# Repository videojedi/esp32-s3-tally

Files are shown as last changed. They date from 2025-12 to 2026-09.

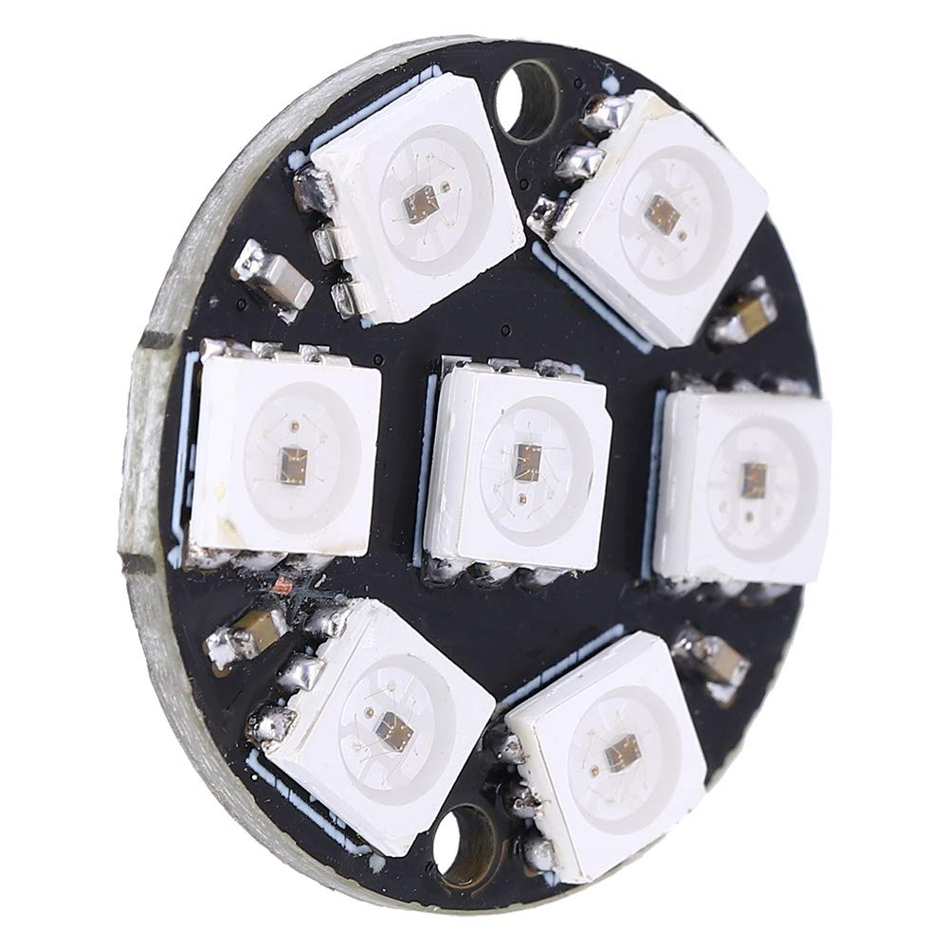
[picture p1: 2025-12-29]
3d files/7LEDring.png

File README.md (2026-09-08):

# ESP32-S3 TSL Tally Light

A TSL 3.1 protocol tally light with web-based configuration, built for ESP32-S3 with W5500 Ethernet.

**Video Walrus 2026**

## Features

- **TSL 3.1 Protocol Support** - Receives multicast UDP tally commands, including brightness
- **Tally Arbiter listener** - Alternative source: follow a device in a Tally Arbiter server (socket.io, like the stock listener clients)
- **Dual-Core Processing** - UDP listener runs on core 0 for reliable packet reception
- **Web Configuration Interface** - Configure all settings via browser
- **Network Priority** - Ethernet preferred, WiFi fallback, AP mode for configuration
- **Auto Device Discovery** - Automatically finds all tally lights on the network via mDNS
- **Bulk Control** - Test all devices simultaneously from any tally's web interface
- **Captive Portal** - Automatic configuration page popup in AP mode
- **Unique Device Identity** - Each device gets a unique hostname based on MAC address
- **mDNS Support** - Access via hostname.local (e.g., `http://Tally-AABBCC.local`)
- **OTA Updates** - Over-the-air firmware updates from the Video Walrus release manifest, or via PlatformIO
- **Persistent Settings** - Configuration stored in NVS flash
- **Factory Reset** - Hold BOOT button for 3 seconds, or use web interface button

## Hardware

### Components

| Component | Description |
|---|---|
| ESP32-S3 DevKitC-1 | Main microcontroller |
| W5500 Ethernet Module | SPI Ethernet PHY |
| WS2812B LED Ring | 7 addressable RGB LEDs (1 middle + 6 ring, e.g. NeoPixel Jewel) |

### Pin Configuration

| Function | GPIO |
|---|---|
| LED Data | 16 |
| ETH CS | 14 |
| ETH SCLK | 13 |
| ETH MISO | 12 |
| ETH MOSI | 11 |
| ETH RST | 9 |
| Factory Reset | 0 (BOOT button) |

### W5500 SPI Ethernet

The W5500 module connects via SPI. These defines must be set before including ETH.h:
- `ETH_PHY_TYPE` = ETH_PHY_W5500
- `ETH_PHY_ADDR` = 1
- `ETH_PHY_CS` = 14 (Chip Select)
- `ETH_PHY_IRQ` = -1 (polled, no interrupt pin)
- `ETH_PHY_RST` = 9 (Reset)
- `ETH_PHY_SPI_HOST` = SPI2_HOST
- `ETH_PHY_SPI_SCK/MISO/MOSI` = 13/12/11

## Web Interface

Open the device IP or `http://<hostname>.local`. Three tabs:

- **Operation** (default): tally state, TSL text, TSL data counter, test buttons, network device list.
- **Configuration**: Tally Source, TSL Settings or Tally Arbiter, and LED Settings.
- **System**: device identity, clock and firmware update, Network and WiFi settings, settings lock, factory reset.

The header shows hostname, IP and connection on every tab, and the page background follows the tally colour. An Auto / Light / Dark switch above the tabs sets the page theme (Auto follows the browser or OS setting); the choice is stored in the browser and also applies to native form controls. The last tab used is remembered in the browser; in AP mode the page opens on System. Configuration and System share one form, so Save on either tab saves both.

**Save** applies most settings immediately: TSL address, max brightness and LED animation take effect without a reboot, and a toast confirms it. The device reboots only when a boot-time setting changed: hostname, IP configuration, WiFi, or the TSL multicast address and port. Hostnames are reduced to letters, digits and hyphens; IP fields that do not parse are ignored. With a settings PIN set, Save asks for it once per browser session (see [Settings Lock](#settings-lock)).

### Status

Operation tab: tally state (Off/Green/Red/Yellow), the TSL text label, and a data line: with the TSL source, packets received for this device's address, the sender and how long ago the last one arrived; with Tally Arbiter, the server, connection state, the assigned device and the update count. Polled every second. System tab: connection type, IP, hostname, MAC, clock (UTC, from SNTP), settings lock state, firmware version with **Check** / **Install** update buttons. The footer shows the firmware build date and time.

### Test Buttons

Manual tally control buttons for testing (momentary - hold to activate):
- **GREEN** - Preview/safe (state 1)
- **RED** - Program/on-air (state 2)
- **YELLOW** - Both tallies active (state 3)

Releasing a button, or dragging off it, returns the light to the last state and brightness received from the switcher (Off if nothing has been received since boot).

### Network Devices

Automatically discovers and displays other tally lights on your network:
- **Auto-discovery** - Devices are scanned on page load, and the firmware rescans in the background every 60 seconds (Ethernet/WiFi only)
- **Scan Network** - Manual refresh button; results are cached for 10 seconds
- Device list shows hostname, TSL address, IP, and a live status dot (polled every 5 seconds)
- **Open** link on each device opens its configuration page
- **Bulk control buttons** - **All GREEN**, **All RED**, **All OFF** set every discovered device plus this one. These are latching, not momentary

### Disco Mode

Type `disco` anywhere on the page (outside a text field) to run a 30-second rainbow party on this device and every discovered device. Tap **Stop** on the overlay to end it early.

### Tally Source

| Setting | Description | Default |
|---|---|---|
| Source | `TSL 3.1 (UDP multicast)` or `Tally Arbiter` (reboots) | TSL 3.1 |

### Tally Arbiter

The tally can be a [Tally Arbiter](https://github.com/josephdadams/TallyArbiter) listener client instead of a TSL receiver. It connects to the server over socket.io (port 4455), registers as a listener and follows one of the server's devices: **program lights red, preview green, both yellow**; other bus types (aux) are ignored. Tally Arbiter has no brightness, so Max Brightness applies.

| Setting | Description | Default |
|---|---|---|
| Server | Hostname or IP of the Tally Arbiter server. **Find server** lists servers announcing `_tally-arbiter._tcp` over mDNS (reboots) | |
| Port | Server port (reboots) | 4455 |
| Device | The Tally Arbiter device to follow, from the list the server sent. **Refresh device list** re-reads it. `Assign from Tally Arbiter` lets the server pick (its first device); applies live | Assign from Tally Arbiter |

The tally appears in Tally Arbiter's listener list as `Video Walrus <hostname>`. **Reassign** and **Flash** from the producer page work: a reassignment is stored on the tally and survives reboots, a flash blinks the ring white three times and returns to the current state. If the server goes away the ring holds its last state and the Operation tab shows "Not connected"; the tally reconnects on its own when the server is back.

### TSL Settings

| Setting | Description | Default |
|---|---|---|
| TSL Address | Tally address 0-126 (applies live) | 0 |
| Multicast Address | TSL multicast group, 224-239.x.x.x (reboots) | 239.1.2.3 |
| TSL Port | UDP port (reboots) | 8901 |

### LED Settings

| Setting | Description | Default |
|---|---|---|
| Max Brightness | LED brightness limit (1-255), applies live | 50 |
| LED Animation | How an active tally is drawn: Solid or Spin, applies live | Solid |

TSL brightness levels map to the LEDs as a fraction of Max Brightness:

| TSL brightness | LED output |
|---|---|
| 0 | Off (dark) |
| 1 | ⅓ of max |
| 2 | ⅔ of max |
| 3 | Max brightness |

**LED Animation** controls how Green, Red and Yellow are shown on the ring. **Solid** lights all seven LEDs. **Spin** keeps the middle LED on at the tally colour, holds the outer six at a dim level and sweeps a bright point with a fading tail round them (one revolution every 0.8 s). Off is always dark. The firmware assumes the middle LED is first in the data chain (`CENTER_LED 0` in main.cpp); set it to 6 if the ring is wired before the middle.

### Network Settings

Hostname, DHCP or static IP (address, gateway, subnet, DNS). Applies to Ethernet and WiFi. Changes here reboot the device.

### WiFi Settings

| Setting | Description |
|---|---|
| WiFi | Disabled, or Enabled (used when Ethernet is down) |
| SSID | WiFi network name |
| Scan for Networks | Lists nearby networks, strongest first, one row per SSID with a lock for secured networks. Tap a row to fill in the SSID. Works in Ethernet, WiFi and AP mode |
| Password | WiFi password. Never shown once stored: leave blank to keep it, type to replace it (a **Show while typing** toggle appears), or tick **Network has no password** to clear it |

Changes here reboot the device.

### Settings Lock

An optional PIN (4 to 16 characters) gates every change made over the network: Save, Reset Defaults, firmware Install, the test buttons, bulk buttons and disco. Status and configuration reads stay open so a monitor wall can watch. The page asks for the PIN once per browser session and sends it with each change; wrong or missing gives HTTP 401. Changing or removing the PIN asks for the current one again, unless the unit was unlocked from its BOOT button. Bulk buttons and disco send this device's PIN to the other tallies they drive, so use the same PIN across a fleet.

**Forgotten PIN:** hold BOOT on the unit for 3 seconds (the ring blinks red) and release: the settings are unlocked for 10 minutes without the PIN, shown on the System tab. Anyone at the box can reflash it over USB anyway, so this costs nothing. Keep holding for 10 seconds to factory reset instead.

The PIN travels over plain HTTP. It protects against accidents and the curious on the LAN, not a determined attacker; put the device on a trusted or segmented network, as with any broadcast control gear.

## Network Modes

The device uses a single network interface at a time for simplicity and reliability:

### Priority Order

1. **Ethernet** - Used exclusively if a link comes up within 10 seconds of boot (best for production)
2. **WiFi** - Falls back if Ethernet unavailable (10 second connect timeout)
3. **AP Mode** - Creates access point if both fail (for initial configuration)

### AP Mode (Fallback)

When no network is available, the device creates its own access point:
- SSID: `Tally-XXYYZZ-Setup` (unique per device)
- Password: `tallytally`
- IP: `192.168.4.1`
- LED indicator: cyan spin, then dim cyan
- **Captive Portal** - Configuration page opens automatically when you connect
- TSL reception, mDNS and PlatformIO OTA are disabled in AP mode

## LED Indicators

| Pattern | Meaning |
|---|---|
| Orange spin | Waiting for Ethernet link |
| Purple spin | Connecting to WiFi |
| Cyan spin | AP mode starting |
| Dim cyan | AP mode active |
| Red blink (BOOT held 3 s) | Release now to unlock the settings for 10 minutes; keep holding for factory reset |
| Red blink, faster (BOOT held 7 s) | Factory reset in 3 seconds, release to abort |
| Blue, then reboot | Factory reset done (BOOT held 10 s) |
| Red, green, blue cycle | Network connected, ready |
| Purple (solid) | Firmware update in progress |
| Green (solid) then reboot | Firmware update succeeded |
| Red (2 s) | Firmware update failed, then back to the current tally |

The boot stages use the same spin animation as the **LED Animation** setting: the middle LED stays on in the stage colour, the outer six glow dimly and a bright point with a fading tail sweeps round them.

### Tally Colors

| State | Color | Description |
|---|---|---|
| 0 | Off (black) | No tally |
| 1 | Green | Preview/safe (tally 1) |
| 2 | Red | Program/on-air (tally 2) |
| 3 | Yellow | Both preview and program |

## TSL 3.1 Protocol

The device listens for TSL 3.1 UMD protocol messages on the configured multicast address and port. Only packets whose address matches the configured TSL Address are acted on.

### Message Format

| Byte | Description |
|---|---|
| 0 | Address + 128 |
| 1 | Control byte (tally + brightness) |
| 2-17 | 16-character text label |

### Control Byte

| Bits | Description |
|---|---|
| 0 | Tally 1 → Green |
| 1 | Tally 2 → Red (both set → Yellow) |
| 2-3 | Tally 3 and 4 (ignored) |
| 4-5 | Brightness (0-3) |

The text label is filtered to printable ASCII and trimmed.

## API Endpoints

| Endpoint | Method | Description |
|---|---|---|
| `/` | GET | Configuration page (static; fills itself from `/api/config` and `/status`) |
| `/status` | GET | JSON status (tally, text, IP, connection, TSL packet count since boot, age and sender) |
| `/api/config` | GET | JSON of every setting plus hostname, MAC, AP details, firmware and build; in Tally Arbiter mode also `taDevices` (the server's device list) and `taDeviceName` |
| `/info` | GET | JSON device info (hostname, MAC, TSL address, firmware, build) |
| `/test?state=N` | GET | Set tally state (0-3) at max brightness |
| `/test?restore=1` | GET | Return to the last state received over TSL |
| `/api/unlock?pin=N` | GET | `{"ok":true}` if the PIN is right, no PIN is set, or the unit is physically unlocked |
| `/api/ta-scan` | GET | Tally Arbiter servers found over mDNS: `{"servers":[{"host","ip","port"}]}` |
| `/discover` | GET | Scan network (cached 10 s) and return found tally devices |
| `/api/wifi-scan` | GET | Start an async WiFi scan (`?start=1`) or return its result; `{"scanning":true}` while running |
| `/disco?duration=N` | GET | Start disco mode for N seconds (1-120, default 30) |
| `/disco-stop` | GET | Stop disco mode and restore the tally state |
| `/api/check-update` | GET | Fetch the release manifest; returns current, latest, date, notes, `error` and `clock` |
| `/api/update` | GET | Download, verify signature, install |
| `/api/update-status` | GET | `fw`, `inProgress`, `error` for the install in progress |
| `/save` | POST | Save settings; applies live, or reboots if network, hostname or TSL socket settings changed |
| `/reset` | GET | Factory reset and reboot |

`/status`, `/test`, `/info`, `/api/unlock`, `/api/update-status`, `/disco` and `/disco-stop` send `Access-Control-Allow-Origin: *` so one tally's page can drive the others. With a settings PIN set, `/save`, `/reset`, `/test`, `/disco`, `/disco-stop` and `/api/update` need `pin=<PIN>` (query or form field) and answer 401 without it. `/api/config` reports `passSet` and `pinSet` instead of the values.

In AP mode, the captive-portal probe URLs (`/generate_204`, `/ncsi.txt`, `/connecttest.txt`, `/hotspot-detect.html`, `/library/test/success.html`) and any unknown path redirect to `/`.

### Status Response

```json
{
  "tally": "Green",
  "text": "CAM 1",
  "ip": "192.168.1.100",
  "connection": "Ethernet",
  "pkts": 1234,
  "age": 480,
  "from": "192.168.1.10",
  "time": 1788950000,
  "pinSet": false,
  "phys": false,
  "physLeft": 0,
  "src": 0,
  "taConn": false,
  "taHost": "",
  "taPort": 4455,
  "taDevice": ""
}
```

`src` is 0 for TSL, 1 for Tally Arbiter; `taConn` and `taDevice` (the device name) describe the Tally Arbiter connection, and `pkts`/`age` then count `device_states` updates from the server.

`pkts` counts packets addressed to this device since boot, `age` is milliseconds since the last one, `from` is its sender. `time` is the SNTP clock (Unix seconds, 0 until synced). `pinSet` says a settings PIN exists, `phys` that the unit was unlocked from its BOOT button, with `physLeft` seconds remaining.

### Info Response

```json
{
  "hostname": "Tally-AABBCC",
  "ip": "192.168.1.100",
  "mac": "AA:BB:CC:DD:EE:FF",
  "tslAddress": 1,
  "tallyState": "Green",
  "tallyText": "CAM 1",
  "connection": "Ethernet",
  "firmware": "1.0.10",
  "build": "Sep  2 2026 18:40:12"
}
```

### Discover Response

```json
{
  "devices": [
    {"hostname": "Tally-112233", "ip": "192.168.1.51", "tslAddress": 2},
    {"hostname": "Tally-445566", "ip": "192.168.1.52", "tslAddress": 3}
  ],
  "count": 2
}
```

## OTA Updates

### From the web page

Click **Check** on the System tab. If a newer version exists a popup lists the release notes with **Install** and **Later**; Install shows progress and reloads the page when the device is back. After an update, the page shows a "What's new" popup once per browser.

The device fetches `https://videowalrus-releases.s3.us-east-1.amazonaws.com/tsl-tally-update.json` (URL in [src/main.cpp](src/main.cpp)), compares `version` with its own, shows the release notes, and on Install downloads the binary at `url`.

Manifest format:

```json
{"version":"1.2.0","url":"https://videowalrus-releases.s3.us-east-1.amazonaws.com/tsl-tally-1.2.0.bin",
 "md5":"...","sha256":"...","sig":"<base64 ECDSA-SHA256 signature>","size":1325000,
 "release_date":"2026-09-07","notes":["...","..."]}
```

### Update security

- **Transport.** Manifest and binary are fetched over TLS validated against Amazon's root certificates compiled into the firmware ([src/certs.h](src/certs.h)). A device that cannot validate the chain refuses to talk. Validation needs the clock, so the device syncs SNTP when online and the update check waits until it has; the System tab shows the clock.
- **Authenticity.** Every release is signed with an ECDSA P-256 key that never enters the repo. `release.sh` reads it from the macOS Keychain (generic password `videowalrus-tsl-tally-signing`, PEM base64-encoded) and falls back to a PEM file at `~/.config/videowalrus/tsl-tally-signing.key` or `SIGNING_KEY=<file>`. The public key is compiled in ([src/signing_key.h](src/signing_key.h)). The device hashes the binary as it streams into the passive partition and verifies the signature before the image is marked bootable; a mismatch aborts and the running firmware stays. This holds even if the bucket or the AWS credentials are compromised.
- **Manifests without a signature are refused** by firmware 1.2.0 and later. `release.sh` checks that the compiled-in public key matches the private key before building, so a release can never be signed with a key the devices don't trust.
- **Key loss.** Losing the private key means no further OTA updates to devices in the field; they would need USB reflashing with a new public key. The login Keychain lives on one Mac, so keep a second copy somewhere encrypted and off the machine. The tally key is separate from the TSL relay's.
- **Older firmware.** 1.1.0 verifies MD5 only and ignores the signature fields, so it can still update to a signed release. 1.0.12 and earlier update from GitHub, where the v1.1.0 release remains as the stepping stone.

**Firmware 1.0.12 and earlier** looks for updates on GitHub releases instead (`https://api.github.com/repos/videojedi/esp32-s3-tally/releases/latest`, asset `firmware.bin`). The v1.1.0 GitHub release exists so those devices can reach the manifest-based firmware; after that they update from S3 like everything else.

### PlatformIO OTA

For development or manual updates:

- Hostname: Configured device hostname
- Password: `password`
- Port: Default (3232)

#### Single Device Update

```bash
# Set target IP and upload
TALLY_IP=192.168.1.100 pio run -t upload -e ota

# Or use mDNS hostname
TALLY_IP=Tally-AABBCC.local pio run -t upload -e ota
```

#### Bulk Update All Devices

Use the included script to update all tally lights on the network:

```bash
# Provide any known device IP - it discovers the rest
./ota-update-all.sh 192.168.1.100
```

The script will:
1. Build the firmware
2. Query the device to discover all tallies on the network
3. Show the device list and ask for confirmation
4. Update each device via OTA
5. Report success/failure summary

### Creating Releases

```bash
./release.sh 1.1.0 "Tabbed web page" "Light and dark themes"
```

Bumps `FIRMWARE_VERSION`, builds, signs the binary, commits, tags, pushes, uploads `tsl-tally-<version>.bin` to S3 and rewrites the manifest with version, URL, MD5, SHA-256, signature, size, date and the notes given as arguments. Safe to rerun for the same version. Needs the AWS CLI and a `.env` in the project root with `AWS_ACCESS_KEY_ID`, `AWS_SECRET_ACCESS_KEY`, `AWS_REGION` and `S3_BUCKET` (not committed).

`GITHUB=1 ./release.sh ...` also creates a GitHub release with `firmware.bin` attached, for devices still on 1.0.12 or earlier.

## Performance and Packet Rates

The receiver drains every queued packet each pass, only looks at the address byte of frames for other addresses, and redraws the LEDs only when the state, brightness or text changed, so a switcher repeating all 127 addresses several times a second costs the tally almost nothing. Measured on the bench with unicast frames it keeps a median response under 50 ms at 1200 packets/s and stays usable at 2500/s.

**Multicast over WiFi is the limit, not the tally.** An access point forwards multicast to WiFi clients at its lowest basic rate, often 1 to 6 Mbit/s on 2.4 GHz, without acknowledgements. A few hundred small TSL frames a second already fill that, frames get dropped and the light lags by seconds; at around 1000 frames/s it stops responding. The same flood as unicast is fine. If a tally on WiFi is slow when the switcher is busy:

- Use Ethernet for that tally (no such limit on the wire).
- Turn on multicast-to-unicast conversion on the access point (UniFi "Multicast enhancement", Cisco/Aruba "multicast to unicast", Ruckus "directed multicast").
- Point the sender at the tally's IP instead of the group. The tally accepts unicast TSL on its port as well as the multicast group.
- Lower the sender's repeat rate if it has one.
- Or run the tally in Tally Arbiter mode, which is a unicast TCP connection.

WiFi modem sleep is disabled in the firmware because it adds tens of milliseconds to every received frame and drops multicast.

## Factory Reset

### Hardware Reset

With the unit running, hold BOOT (GPIO 0). After 3 seconds the ring blinks red; keep holding and the blink speeds up at 7 seconds. At 10 seconds the ring turns blue, settings are erased and the unit reboots into AP mode. Release before 10 seconds and nothing is erased (releasing after 3 seconds unlocks the settings instead, see [Settings Lock](#settings-lock)). Do not hold BOOT while powering on or pressing RESET: GPIO 0 low at reset enters the USB bootloader instead of the firmware.

### Web Interface Reset
1. Open the device configuration page, System tab
2. Click "Reset Defaults" and confirm (asks for the PIN if one is set)
3. Device reboots with factory settings

## Building

### Requirements

- PlatformIO
- ESP32 Arduino framework 3.x

### Build Commands

```bash
# Build
pio run

# Upload over USB
pio run -t upload

# Monitor serial (115200 baud; the firmware waits 3 s at boot for the port)
pio device monitor
```

### platformio.ini

```ini
[platformio]
default_envs = esp32-s3

[env:esp32-s3]
platform = espressif32
board = esp32-s3-devkitc-1
framework = arduino
monitor_speed = 115200
lib_deps =
    fastled/FastLED@3.9.3
build_flags =
    -DARDUINO_USB_MODE=1
    -DARDUINO_USB_CDC_ON_BOOT=1
upload_speed = 921600

[env:ota]
extends = env:esp32-s3
upload_protocol = espota
upload_port = ${sysenv.TALLY_IP}
upload_flags =
    --auth=password
```

`default_envs` keeps IDE build/upload buttons on the USB environment; use `-e ota` explicitly for OTA.

## Architecture

### Dual-Core Design

- **Core 0**: the tally source task: the UDP listener (polls for TSL packets every 5 ms) or the Tally Arbiter socket.io client (`src/arbiter.cpp`), whichever the Tally Source setting selects
- **Core 1**: Main loop - web server, captive-portal DNS, OTA, disco animation, background discovery

This separation ensures reliable multicast reception even when the web interface is active.

### Libraries Used

- FastLED - WS2812B LED control
- ETH / SPI - W5500 Ethernet
- WiFi - Station and AP modes
- WebServer - HTTP server
- Preferences - NVS storage
- ESPmDNS - mDNS responder and service discovery (`_tally._tcp` with TXT records)
- NetworkUdp - UDP multicast
- ArduinoOTA - Over-the-air updates
- HTTPClient / WiFiClientSecure / Update - firmware updates from the release manifest over pinned TLS
- mbedtls (sha256, pk, base64) - firmware signature verification
- WebSockets (Links2004) - socket.io client for Tally Arbiter
- ArduinoJson - Tally Arbiter message parsing
- DNSServer - Captive portal support

## License

MIT License - Video Walrus 2026

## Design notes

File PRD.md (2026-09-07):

# ESP32-S3 TSL Tally Light - Product Requirements Document

## Product Overview

A professional-grade TSL 3.1/5.0 protocol tally light system built on ESP32-S3 with W5500 Ethernet. Designed for broadcast, live production, and streaming environments where camera operators need clear on-air/preview status indication.

**Version:** 1.0.8
**Author:** Video Walrus
**Copyright:** 2026 Video Walrus

## Problem Statement

Camera operators in live production environments need immediate visual feedback when their camera is selected for program (on-air) or preview. Traditional tally systems require proprietary hardware and complex wiring. This solution provides:

- Affordable, open-source tally lights using commodity hardware
- Network-based operation eliminating proprietary wiring
- Web-based configuration requiring no special software
- Multi-device management from any tally's web interface

## Target Users

1. **Broadcast Engineers** - Setting up multi-camera productions
2. **Live Event Producers** - Corporate events, worship, sports
3. **Content Creators** - Streamers and YouTubers with multi-camera setups
4. **Technical Directors** - Managing camera status in control rooms

## Hardware Requirements

### Core Components

| Component | Specification | Purpose |
|---|---|---|
| ESP32-S3 DevKitC-1 | Dual-core, 240MHz | Main processor |
| W5500 Ethernet Module | SPI interface | Wired network connectivity |
| WS2812B LED Strip | 7 addressable RGB LEDs | Tally status display |

### Pin Configuration

| Function | GPIO | Notes |
|---|---|---|
| LED Data | 16 | WS2812B data line |
| ETH CS | 14 | W5500 chip select |
| ETH SCLK | 13 | SPI clock |
| ETH MISO | 12 | SPI data in |
| ETH MOSI | 11 | SPI data out |
| ETH RST | 9 | W5500 reset |
| Factory Reset | 0 | BOOT button |

## Functional Requirements

### FR-1: TSL Protocol Support (3.1 & 5.0)

**Priority:** Critical

The device shall receive and process TSL 3.1 and TSL 5.0 UMD protocol messages via UDP multicast. Protocol version is auto-detected.

| Requirement | Implementation |
|---|---|
| Multicast group | Configurable (default: 239.1.2.3) |
| UDP port | Configurable (default: 8901) |
| Address range | 0-126 |
| Tally states | Off (0), Green (1), Red (2), Yellow (3), Blue (4), Magenta (5), Cyan (6) |
| Brightness levels | 0-3, mapped to configurable max |
| Text label | 16-character display name |

**TSL 3.1 Message Format:**
- Byte 0: Address + 128
- Byte 1: Control byte (bits 0-3: tally state, bits 4-5: brightness)
- Bytes 2-17: 16-character text label

**TSL 5.0 UMD Message Format:**
- Byte 0: PBC (Packet Byte Count - 1)
- Byte 1: VER (Version, 0x00 for UMD)
- Bytes 2-3: FLAGS (little endian)
- Bytes 4-5: SCREEN (little endian)
- Bytes 6-7: INDEX (little endian) - display address
- Bytes 8-9: CONTROL (little endian) - tally and brightness
- Bytes 10+: Text (null terminated)

**Alternative source: Tally Arbiter.** With Tally Source set to Tally Arbiter the device registers as a listener client with a Tally Arbiter server (socket.io, port 4455) and follows one of its devices: program → red, preview → green, both → yellow. Device assignment from the tally's page or from Tally Arbiter's producer page; flash supported.

### FR-2: Network Connectivity

**Priority:** Critical

The device shall support multiple network connection methods with automatic fallback.

**Priority Order:**
1. **Ethernet** (W5500) - Primary, most reliable
2. **WiFi Client** - Secondary, if Ethernet unavailable
3. **Access Point** - Fallback for initial configuration

| Feature | Specification |
|---|---|
| Ethernet | W5500 SPI, 10/100 Mbps |
| WiFi | 802.11 b/g/n, 2.4GHz |
| AP Mode SSID | Tally-XXYYZZ-Setup (unique per device) |
| AP Password | tallytally |
| AP IP | 192.168.4.1 |
| DHCP | Supported (default) |
| Static IP | Configurable |

### FR-3: Web Configuration Interface

**Priority:** Critical

The device shall provide a responsive web interface accessible via HTTP.

**Configuration Options:**
- TSL Settings: Address, multicast IP, port, max brightness
- WiFi Settings: Enable/disable, SSID, password
- Ethernet Settings: Hostname, DHCP/Static, IP configuration
- Factory Reset: Clear all settings

**Status Display:**
- Connection type (Ethernet/WiFi/AP)
- IP address
- Tally state with color indicator
- TSL text label
- MAC addresses
- Firmware version

**Test Controls:**
- Momentary Green, Red, Yellow buttons
- Hold to activate, release to return to off

### FR-4: Multi-Device Discovery

**Priority:** High

The device shall discover other tally lights on the network via mDNS.

| Feature | Implementation |
|---|---|
| Service type | _tally._tcp |
| Discovery method | mDNS query |
| Auto-scan interval | 60 seconds |
| Manual scan | Button in web UI |
| Device limit | 16 devices |

**Device Info Exposed:**
- Hostname
- IP address
- TSL address
- Firmware version
- MAC address

### FR-5: Bulk Control

**Priority:** High

The device shall support controlling all discovered devices simultaneously.

**Bulk Actions:**
- Set all devices to Green
- Set all devices to Red
- Set all devices to Off

**Implementation:** Cross-origin AJAX requests to each device's `/test` endpoint.

### FR-6: OTA Updates

**Priority:** High

The device shall support over-the-air firmware updates via two methods.

**Method 1: ArduinoOTA (Development)**
- Port: 3232 (default)
- Password: `password`
- Requires PlatformIO

**Method 2: Release Manifest (Production)**
- Version check against the Video Walrus S3 manifest (`tsl-tally-update.json`); release notes and date shown in the web UI
- TLS to S3 validated against Amazon root CAs compiled in; SNTP clock required for certificate dates
- Every release signed with ECDSA P-256; the device hashes the download and verifies the signature before the image is marked bootable, and refuses unsigned manifests
- MD5 from the manifest also verified
- One-click download and install from web UI
- Progress indication via LED (purple during update)
- Automatic reboot after successful update

### FR-7: Persistent Storage

**Priority:** Critical

All configuration shall persist across power cycles using ESP32 NVS (Non-Volatile Storage).

**Stored Settings:**
- Tally source (TSL / Tally Arbiter), TSL address, multicast IP, port, Tally Arbiter host, port and device, max brightness, LED animation (Solid/Spin), settings PIN
- Settings apply live unless network, hostname or TSL socket settings changed (then reboot)
- Network mode (DHCP/Static), static IP configuration
- WiFi enabled flag, SSID, password
- Device hostname

### FR-8: Factory Reset

**Priority:** High

The device shall support two methods of factory reset.

**Hardware Reset:**
1. With the unit running, hold BOOT
2. Ring blinks red from 3 s, faster from 7 s
3. At 10 s the ring turns blue, settings are erased, device reboots
4. Release before 10 s to abort (release after 3 s unlocks the settings for 10 minutes)

**Web Interface Reset:**
1. Click "Reset Defaults" button
2. Confirm in dialog (PIN if set)
3. All settings cleared, device reboots

### FR-9: LED Status Indicators

**Priority:** Medium

The device shall provide visual feedback via LED patterns.

| Pattern | Meaning |
|---|---|
| Orange spin | Waiting for Ethernet |
| Purple spin | Connecting to WiFi |
| Cyan spin | AP mode started |
| Dim cyan | AP mode active |
| Red blink | Factory reset in progress |
| Blue flash | Factory reset complete |
| Color cycle | Network connected, ready |

**Tally Colors:**
| State | Color | Description |
|---|---|---|
| 0 | Off (black) | No tally |
| 1 | Green | Preview/safe |
| 2 | Red | Program/on-air |
| 3 | Yellow | Both preview and program |
| 4 | Blue | Extended (TSL 5.0 Tally 3) |
| 5 | Magenta | Extended (TSL 5.0 Tally 4) |
| 6 | Cyan | Extended (TSL 5.0 Tally 3+4) |

### FR-10: Captive Portal

**Priority:** Medium

When in AP mode, the device shall trigger captive portal detection on client devices.

**Supported Platforms:**
- Android (`/generate_204`)
- Windows (`/ncsi.txt`, `/connecttest.txt`)
- Apple (`/hotspot-detect.html`, `/library/test/success.html`)

**Behavior:** Redirect all captive portal probes to configuration page.

### FR-11: Disco Mode (Easter Egg)

**Priority:** Low

Type "disco" on any page to activate party mode.

**Features:**
- Activates on local and all discovered devices
- Random rainbow color cycling at 250ms intervals
- Full brightness override
- 30-second duration (configurable)
- Cancellable via "STOP THE PARTY" button

## API Endpoints

| Endpoint | Method | Description |
|---|---|---|
| `/` | GET | Configuration page |
| `/status` | GET | JSON: tally, text, IP, connection |
| `/info` | GET | JSON: hostname, MAC, TSL addr, firmware |
| `/test?state=N` | GET | Set tally state (0-6) |
| `/discover` | GET | Scan network, return devices |
| `/api/check-update` | GET | Check the release manifest for updates |
| `/api/update` | GET | Download and install update |
| `/save` | POST | Save settings, reboot |
| `/reset` | GET | Factory reset, reboot |
| `/disco?duration=N` | GET | Activate disco mode |
| `/disco-stop` | GET | Deactivate disco mode |

**CORS:** All status/control endpoints include `Access-Control-Allow-Origin: *` for cross-device communication.

## Non-Functional Requirements

### NFR-1: Performance

| Metric | Requirement |
|---|---|
| Tally response time | < 50ms from packet receipt |
| Web UI load time | < 2 seconds |
| Boot time to ready | < 10 seconds |
| UDP polling interval | 5ms |

### NFR-2: Reliability

| Metric | Requirement |
|---|---|
| Uptime | 99.9% during production |
| Network recovery | Auto-reconnect on disconnect |
| Watchdog | Enabled, prevents lockups |

### NFR-3: Dual-Core Architecture

- **Core 0:** UDP listener task - dedicated to TSL packet reception
- **Core 1:** Main loop - web server, OTA, LED control, mDNS

This separation ensures reliable multicast reception even during web interface activity.

## Dependencies

### Libraries

| Library | Version | Purpose |
|---|---|---|
| FastLED | 3.9.3 | WS2812B LED control |
| ESPAsyncWebServer | 1.2.3 | HTTP server |
| AsyncTCP | 1.1.1 | Async TCP for web server |
| ArduinoOTA | Built-in | OTA updates |
| ESPmDNS | Built-in | mDNS responder/discovery |
| Preferences | Built-in | NVS storage |
| HTTPClient | Built-in | Release manifest and firmware download |
| WiFiClientSecure | Built-in | HTTPS to S3 |

### Build Environment

- PlatformIO
- ESP32 Arduino Framework
- Board: esp32-s3-devkitc-1

## Security Considerations

| Risk | Mitigation |
|---|---|
| OTA password | Default "password" - should be changed for production |
| No HTTPS | Local network only, not exposed to internet |
| No authentication | Web UI open access - assumes trusted network |
| Manifest OTA | Pinned TLS (Amazon roots), signed firmware (ECDSA P-256), MD5 |
| Settings lock | Optional PIN over plain HTTP; BOOT button unlock for 10 min; against accidents and LAN curiosity, not a determined attacker |

## Future Enhancements (Backlog)

1. **Authentication** - Optional login for web interface
2. **HTTPS** - Self-signed certificate support
3. **Multiple Addresses** - Monitor multiple TSL addresses
4. **Custom Colors** - User-defined tally colors
5. **Battery Support** - Low-power mode for portable operation
6. **PoE** - Power over Ethernet support
7. **TSL 5.0** - Modern protocol support
8. **DMX Output** - Trigger external tally lights
9. **REST Webhooks** - Notify external systems of state changes

## Testing Requirements

### Unit Tests
- TSL message parsing
- Version comparison
- IP address validation

### Integration Tests
- Multicast reception
- mDNS discovery
- Release manifest fetch
- NVS persistence

### Manual Tests
- Factory reset (button and web)
- Network failover (Ethernet → WiFi → AP)
- OTA update from the release manifest
- Multi-device bulk control
- Disco mode synchronization

## Release Process

1. `./release.sh <version> "note" ...` bumps `FIRMWARE_VERSION`, builds, commits, tags and pushes
2. Uploads `tsl-tally-<version>.bin` and `tsl-tally-update.json` to S3
3. `GITHUB=1` also creates a GitHub release with `firmware.bin` for devices on 1.0.12 or earlier
4. Devices can now check for and install the update

**Release Script:** `./release.sh <version>`

## Appendix A: Switcher Compatibility

| Switcher | TSL Output | Notes |
|---|---|---|
| Blackmagic ATEM | Native | Multicast 239.1.2.3:8901 |
| vMix | Native | TSL 3.1 UDP output |
| OBS | Plugin required | Third-party TSL plugin |
| Tricaster | Native | Configure multicast |
| Ross | Native | TSL UMD support |

## Appendix B: Troubleshooting

| Symptom | Possible Cause | Solution |
|---|---|---|
| No LED response | Power issue | Check USB cable |
| Can't find device | Network mismatch | Use AP mode for config |
| Tally not responding | Wrong address | Verify TSL address matches |
| Wrong colors | Address conflict | Check for duplicate addresses |
| OTA fails | Network timeout | Try wired Ethernet |

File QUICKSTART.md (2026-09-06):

# Quick Start Guide

Get your TSL Tally Light up and running in minutes.

## What You Need

- ESP32-S3 tally light (assembled with W5500 Ethernet module)
- Ethernet cable OR WiFi network
- Computer or phone with web browser
- TSL 3.1 compatible video switcher (ATEM, vMix, etc.)

## Step 1: Power On

Connect USB-C power to the ESP32-S3. The LED will show startup indicators:

| LED Pattern | Meaning |
|---|---|
| Orange spin | Looking for Ethernet |
| Purple spin | Connecting to WiFi |
| Cyan spin, then dim cyan | AP mode (no network found) |
| Red, green, blue cycle | Connected and ready |

## Step 2: Connect to the Device

### Option A: Ethernet (Recommended)

1. Plug in an Ethernet cable
2. The device gets an IP via DHCP
3. Find the IP in your router's DHCP client list, or use:
   - `http://Tally-XXXXXX.local` (where XXXXXX is shown on serial output)

### Option B: WiFi Setup Mode

If no Ethernet is connected and WiFi isn't configured:

1. The device creates a WiFi hotspot:
   - **SSID:** `Tally-XXXXXX-Setup`
   - **Password:** `tallytally`
2. Connect your phone/computer to this network
3. A configuration page should open automatically
4. If not, go to `http://192.168.4.1`

## Step 3: Configure Settings

Open the web interface and set:

### TSL Settings
- **TSL Address:** Match your switcher's tally output (0-126)
- **Multicast Address:** Usually `239.1.2.3` (check your switcher)
- **TSL Port:** Usually `8901`
- **Max Brightness:** Start with 50, increase if needed

### Network Settings
- **Hostname:** Give it a memorable name like `CAM1` or `Guest`
- **WiFi:** Enable, then **Scan for Networks** and tap your network (or type the SSID) and enter the password if you want WiFi fallback

Click **Save Settings**. The device will reboot.

## Step 4: Configure Your Switcher

Set up your video switcher to send TSL 3.1 tally data:

### Blackmagic ATEM
1. ATEM Software Control → Preferences → Network
2. Enable "Tally Output"
3. Set multicast address to `239.1.2.3`

### vMix
1. Settings → Tally
2. Enable TSL 3.1 UDP
3. Set destination to multicast `239.1.2.3:8901`

### OBS (with plugin)
Use a TSL tally plugin to send multicast tally data.

## Step 5: Test It

On the web interface, use the test buttons:
- Hold **GREEN** - Preview/safe
- Hold **RED** - Program/on-air
- Hold **YELLOW** - Both preview and program

Releasing a button returns the light to whatever the switcher last sent.

Then test with your actual switcher by selecting the camera.

## Troubleshooting

### No LED response
- Check USB power connection
- Try a different USB cable/power source

### Can't find device on network
- Check Ethernet cable is connected
- Try the AP mode setup (disconnect Ethernet, reboot)
- Check your router's DHCP client list

### Tally not responding to switcher
- Verify TSL address matches switcher output
- Check multicast address and port match
- Ensure switcher and tally are on same network/VLAN
- Some networks block multicast - check with IT

### Wrong colors showing
- TSL address might be wrong - check switcher config
- Another device might have the same address

## Factory Reset

If you need to start over:

1. Power on the device
2. Hold the **BOOT** button (small button on ESP32)
3. Wait for red blinking (~3 seconds)
4. Release when LED turns blue
5. Device resets to defaults and reboots into AP mode

## Multiple Devices

Setting up multiple tally lights:

1. Each device has a unique hostname based on its MAC address
2. Give each a different TSL address (matching your switcher outputs)
3. Use the **Network Devices** section in the web UI to discover and manage all tallies
4. **Bulk control** buttons let you test all devices at once

## Network Tips

- **Use Ethernet** for production - more reliable than WiFi
- **Same subnet** - Tally and switcher must be on the same network
- **Multicast routing** - If using VLANs, ensure multicast is routed
- **Static IP** - Optional, but useful for fixed installations

---

Need help? Check the full [README.md](README.md) for detailed documentation.

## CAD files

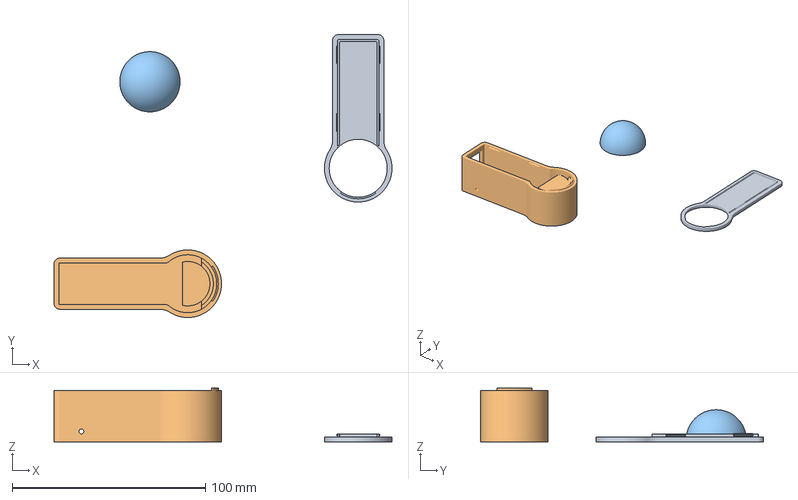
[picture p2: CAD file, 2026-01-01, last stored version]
3d files/housing.3mf
175.1 x 146.6 x 27.8 mm
SoC - top5.stl
SoC - base5.stl
SoC - newDome5.stl

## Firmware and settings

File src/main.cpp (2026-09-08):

/*
    ESP32-S3 TSL Tally Light with Web Configuration
    Video Walrus 2025
*/

#include <Arduino.h>
#include <FastLED.h>
#include <Preferences.h>
#include <WebServer.h>
#include <WiFi.h>

#define BUFFER_LENGTH 256
#define NUM_LEDS 7
#define DATA_PIN 16
#define RESET_BUTTON_PIN 0  // GPIO 0 (BOOT button) for factory reset
#define WIFI_CONNECT_TIMEOUT 10000  // 10 seconds to connect to WiFi
#ifndef FIRMWARE_VERSION
#define FIRMWARE_VERSION "1.3.0"
#endif
#define MAX_DISCOVERED_DEVICES 16

// W5500 SPI Ethernet configuration - MUST be defined BEFORE including ETH.h
#define ETH_PHY_TYPE    ETH_PHY_W5500
#define ETH_PHY_ADDR    1
#define ETH_PHY_CS      14
#define ETH_PHY_IRQ     -1
#define ETH_PHY_RST     9
#define ETH_PHY_SPI_HOST SPI2_HOST
#define ETH_PHY_SPI_SCK  13
#define ETH_PHY_SPI_MISO 12
#define ETH_PHY_SPI_MOSI 11

#include <ETH.h>
#include <SPI.h>
#include <NetworkUdp.h>
#include <ArduinoOTA.h>
#include <ESPmDNS.h>
#include <DNSServer.h>
#include <HTTPClient.h>
#include <WiFiClientSecure.h>
#include <Update.h>
#include "webpage.h"
#include <time.h>
#include <mbedtls/sha256.h>
#include <mbedtls/pk.h>
#include <mbedtls/base64.h>
#include "certs.h"
#include "signing_key.h"
#include "arbiter.h"

// OTA update manifest published by release.sh (see otaCheck). A build flag can override
// the URL so a test build points at a test manifest.
#ifndef MANIFEST_URL
#define MANIFEST_URL "https://videowalrus-releases.s3.us-east-1.amazonaws.com/tsl-tally-update.json"
#endif
#define OTA_MAX_NOTES 8
#define OTA_MIN_EPOCH 1750000000UL  // mid 2025; anything earlier means SNTP has not run
#define OTA_STALL_MS  30000

// BOOT button timing (see buttonTick)
#define BTN_UNLOCK_MS    3000
#define BTN_FAST_FROM_MS 7000
#define BTN_RESET_MS     10000
#define UNLOCK_WINDOW_MS (10UL * 60UL * 1000UL)

// Forward declarations
void loadSettings();
void saveSettings();
void resetSettings();
void buttonTick();
void onEvent(arduino_event_id_t event);
void setupWebServer();
bool udpTSL(const char *data, int len);
void setTallyState(int state, int brightness = -1);  // brightness < 0 = maxBrightness
void renderSpinFrame(CRGB colour, uint8_t brightness);
void spinDelay(CRGB colour, unsigned long ms);
void ledLock();
void ledUnlock();
void ledShowSolid(CRGB colour);
bool setupWiFi();
void startAP();
String getActiveIP();
void startUDP();
void stopUDP();
void udpListenerTask(void *pvParameters);
void startUDPTask();
void stopUDPTask();
void startMDNS();
void testLED();
void discoverTallyDevices();
String getDefaultHostname();
String htmlEscape(const String& s);
String jsonEscape(const String& s);

// Web server
WebServer server(80);
DNSServer dnsServer;
Preferences preferences;

// Configurable settings (loaded from NVS)
int tslAddress = 0;
int maxBrightness = 50;  // Max brightness (0-255), TSL brightness maps to this
enum LedAnimation { LED_ANIM_SOLID = 0, LED_ANIM_SPIN = 1 };
int ledAnimation = LED_ANIM_SOLID;  // How an active tally is drawn on the ring
String settingsPin = "";  // Settings lock PIN, "" = no lock
enum TallySource { SOURCE_TSL = 0, SOURCE_ARBITER = 1 };
int tallySource = SOURCE_TSL;       // where the tally state comes from
String taHost = "";                 // Tally Arbiter server host or IP
int taPort = 4455;
String taDeviceId = "unassigned";   // Tally Arbiter device we follow
int tslPort = 8901;      // TSL multicast port
String tslMulticast = "239.1.2.3";  // TSL multicast address
bool useDHCP = true;
String staticIP = "192.168.1.100";
String gateway = "192.168.1.1";
String subnet = "255.255.255.0";
String dns = "8.8.8.8";
String deviceHostname = "ESP-TSL-Tally";

// WiFi settings
String wifiSSID = "";
String wifiPassword = "";
bool wifiEnabled = false;

// AP settings
String apSSID = "TSL-Tally-Setup";
String apPassword = "tallytally";

bool redTally = false;
int redLED = false;
bool greenTally = false;
int greenLED = false;

IPAddress multicastAddress;

// Synchronous UDP for dedicated task
NetworkUDP udp;

// FreeRTOS task handle for UDP listener
TaskHandle_t udpTaskHandle = NULL;
volatile bool udpRunning = false;

CRGB leds[NUM_LEDS];

// The LEDs are written from two cores: the UDP task (core 0) on every TSL packet and
// loop() (core 1) for animation frames. ledMutex serialises brightness + fill + show.
SemaphoreHandle_t ledMutex = NULL;
SemaphoreHandle_t nvsMutex = NULL;  // saveSettings() from the web server and the Tally Arbiter task
// Active tally as last set by setTallyState(); loop() keeps the spin animation turning
static CRGB tallyColour = CRGB::Black;
static uint8_t tallyLevel = 0;
static volatile bool spinActive = false;

static bool eth_connected = false;
static bool wifi_connected = false;
static bool ap_mode = false;
static bool discoMode = false;
static unsigned long discoEndTime = 0;
String currentTallyState = "Off";
String currentTallyText = "";
// Last state/brightness received over TSL; restored when a test button is released
volatile int tslState = 0;
volatile int tslBrightness = -1;
volatile int tslBrightRaw = -1;  // 0-3 as received, -1 = nothing received yet
// Packets received for this address, shown on the status page
volatile uint32_t tslPackets = 0;
volatile unsigned long tslLastMs = 0;
volatile uint32_t tslLastFrom = 0;  // IPv4 of the last sender

// Structure for discovered tally devices
struct TallyDevice {
  String hostname;
  String ip;
  int tslAddress;
  String tallyState;
  unsigned long lastSeen;
  bool online;
};

TallyDevice discoveredDevices[MAX_DISCOVERED_DEVICES];
int numDiscoveredDevices = 0;
unsigned long lastDiscoveryScan = 0;

// OTA update state, from the release manifest
String latestVersion = "";
String firmwareURL = "";
String firmwareMD5 = "";
String firmwareSHA256 = "";
String firmwareSig = "";
String releaseDate = "";
String otaLastError = "";  // why the last check or install failed, "" if it did not
String otaNotes[OTA_MAX_NOTES];
int otaNoteCount = 0;
bool updateAvailable = false;
volatile bool updateInProgress = false;

// Generate unique default hostname using ESP32 base MAC address
String getDefaultHostname() {
  uint64_t chipid = ESP.getEfuseMac();  // Factory-programmed MAC, always available
  char hostname[20];
  // Use last 3 bytes of MAC for uniqueness: Tally-XXYYZZ
  snprintf(hostname, sizeof(hostname), "Tally-%02X%02X%02X",
           (uint8_t)(chipid >> 24), (uint8_t)(chipid >> 32), (uint8_t)(chipid >> 40));
  return String(hostname);
}

// Load settings from NVS
void loadSettings() {
  preferences.begin("tally", true);  // read-only
  tslAddress = preferences.getInt("tslAddress", 0);
  maxBrightness = preferences.getInt("maxBright", 50);
  ledAnimation = preferences.getInt("ledAnim", LED_ANIM_SOLID);
  settingsPin = preferences.getString("pin", "");
  tallySource = preferences.getInt("src", SOURCE_TSL);
  taHost = preferences.getString("taHost", "");
  taPort = preferences.getInt("taPort", 4455);
  taDeviceId = preferences.getString("taDevice", "unassigned");
  tslPort = preferences.getInt("tslPort", 8901);
  tslMulticast = preferences.getString("tslMcast", "239.1.2.3");
  useDHCP = preferences.getBool("useDHCP", true);
  staticIP = preferences.getString("staticIP", "192.168.1.100");
  gateway = preferences.getString("gateway", "192.168.1.1");
  subnet = preferences.getString("subnet", "255.255.255.0");
  dns = preferences.getString("dns", "8.8.8.8");
  deviceHostname = preferences.getString("hostname", getDefaultHostname());
  wifiSSID = preferences.getString("wifiSSID", "");
  wifiPassword = preferences.getString("wifiPass", "");
  wifiEnabled = preferences.getBool("wifiEnabled", false);
  preferences.end();

  Serial.println("Settings loaded:");
  Serial.printf("  TSL Address: %d\n", tslAddress);
  Serial.printf("  TSL Multicast: %s\n", tslMulticast.c_str());
  Serial.printf("  TSL Port: %d\n", tslPort);
  Serial.printf("  Max Brightness: %d\n", maxBrightness);
  Serial.printf("  LED Animation: %s\n", ledAnimation == LED_ANIM_SPIN ? "Spin" : "Solid");
  Serial.printf("  Settings lock: %s\n", settingsPin.length() ? "PIN set" : "off");
  Serial.printf("  Tally source: %s\n", tallySource == SOURCE_ARBITER ? "Tally Arbiter" : "TSL 3.1");
  if (tallySource == SOURCE_ARBITER) Serial.printf("  Tally Arbiter: %s:%d device %s\n", taHost.c_str(), taPort, taDeviceId.c_str());
  Serial.printf("  DHCP: %s\n", useDHCP ? "Yes" : "No");
  if (!useDHCP) {
    Serial.printf("  Static IP: %s\n", staticIP.c_str());
    Serial.printf("  Gateway: %s\n", gateway.c_str());
    Serial.printf("  Subnet: %s\n", subnet.c_str());
    Serial.printf("  DNS: %s\n", dns.c_str());
  }
  Serial.printf("  Hostname: %s\n", deviceHostname.c_str());
  Serial.printf("  WiFi Enabled: %s\n", wifiEnabled ? "Yes" : "No");
  if (wifiEnabled && wifiSSID.length() > 0) {
    Serial.printf("  WiFi SSID: %s\n", wifiSSID.c_str());
  }
}

// Save settings to NVS
void saveSettings() {
  if (nvsMutex) xSemaphoreTake(nvsMutex, portMAX_DELAY);
  preferences.begin("tally", false);  // read-write
  preferences.putInt("tslAddress", tslAddress);
  preferences.putInt("maxBright", maxBrightness);
  preferences.putInt("ledAnim", ledAnimation);
  preferences.putString("pin", settingsPin);
  preferences.putInt("src", tallySource);
  preferences.putString("taHost", taHost);
  preferences.putInt("taPort", taPort);
  preferences.putString("taDevice", taDeviceId);
  preferences.putInt("tslPort", tslPort);
  preferences.putString("tslMcast", tslMulticast);
  preferences.putBool("useDHCP", useDHCP);
  preferences.putString("staticIP", staticIP);
  preferences.putString("gateway", gateway);
  preferences.putString("subnet", subnet);
  preferences.putString("dns", dns);
  preferences.putString("hostname", deviceHostname);
  preferences.putString("wifiSSID", wifiSSID);
  preferences.putString("wifiPass", wifiPassword);
  preferences.putBool("wifiEnabled", wifiEnabled);
  preferences.end();
  if (nvsMutex) xSemaphoreGive(nvsMutex);
  Serial.println("Settings saved to NVS");
}

// Reset settings to factory defaults
void resetSettings() {
  preferences.begin("tally", false);
  preferences.clear();
  preferences.end();
  Serial.println("Settings reset to factory defaults");

  // Reset to defaults in memory
  tslAddress = 0;
  maxBrightness = 50;
  ledAnimation = LED_ANIM_SOLID;
  settingsPin = "";
  tallySource = SOURCE_TSL;
  taHost = "";
  taPort = 4455;
  taDeviceId = "unassigned";
  tslPort = 8901;
  tslMulticast = "239.1.2.3";
  useDHCP = true;
  staticIP = "192.168.1.100";
  gateway = "192.168.1.1";
  subnet = "255.255.255.0";
  dns = "8.8.8.8";
  deviceHostname = getDefaultHostname();
  wifiSSID = "";
  wifiPassword = "";
  wifiEnabled = false;
}

// ---- Settings lock ----
// An optional PIN gates changes from the network; reads stay open. Holding BOOT on the
// unit for 3 s unlocks for a while without the PIN: anyone at the box can already reflash
// it over USB, so the lock is against accidents and the curious on the LAN, not against
// physical access.
static uint32_t unlockUntil = 0;

bool lockPinSet() { return settingsPin.length() > 0; }

bool lockPhysicallyUnlocked() {
  return unlockUntil != 0 && (int32_t)(unlockUntil - millis()) > 0;
}

uint32_t lockPhysicalRemainingMs() {
  return lockPhysicallyUnlocked() ? unlockUntil - millis() : 0;
}

void lockPhysicalUnlock(uint32_t ms) { unlockUntil = millis() + ms; }

// Compare without leaking length or position through timing. Overkill for a LAN PIN, cheap anyway.
static bool pinEquals(const String& a, const String& b) {
  uint8_t diff = a.length() != b.length();
  for (size_t i = 0; i < a.length() && i < b.length(); i++) diff |= a[i] ^ b[i];
  return diff == 0;
}

// No PIN configured, physically unlocked, or the PIN matches
bool lockAuthorised(const String& pin) {
  if (!lockPinSet()) return true;
  if (lockPhysicallyUnlocked()) return true;
  return pin.length() > 0 && pinEquals(pin, settingsPin);
}

// Printable, no spaces, max 16; "" if shorter than 4
String lockSanitisePin(const String& s) {
  String out;
  for (size_t i = 0; i < s.length() && out.length() < 16; i++) {
    char c = s[i];
    if (c > 32 && c < 127) out += c;
  }
  return out.length() >= 4 ? out : String();
}

// ---- LED ring animation ----
// The seven LEDs are one in the middle and six in a ring around it. The spin animation
// keeps the middle LED on at full colour, holds the ring at a dim base level and sweeps
// a bright head with a fading tail round the six once per SPIN_PERIOD_MS. It draws an
// active tally when LED Animation is set to Spin, and the Ethernet / WiFi / AP stages
// of boot.
#define CENTER_LED 0        // data-order index of the middle LED: 0 (NeoPixel Jewel) or 6
#define RING_LEDS (NUM_LEDS - 1)
#define SPIN_PERIOD_MS 800  // one revolution
#define SPIN_BASE 40        // level (0-255) of LEDs away from the head
#define SPIN_LEAD 128       // ramp-up ahead of the head, in 1/256 LED
#define SPIN_TAIL 512       // fade-out behind the head, in 1/256 LED

void ledLock() {
  if (ledMutex) xSemaphoreTake(ledMutex, portMAX_DELAY);
}

void ledUnlock() {
  if (ledMutex) xSemaphoreGive(ledMutex);
}

// Draw one frame of the spin animation for the current millis(). Callers that can run
// concurrently with the UDP task must hold ledMutex.
void renderSpinFrame(CRGB colour, uint8_t brightness) {
  const int32_t ring = RING_LEDS * 256;  // circumference in 1/256 LED
  int32_t head = ((millis() % SPIN_PERIOD_MS) * ring) / SPIN_PERIOD_MS;
  leds[CENTER_LED] = colour;  // middle LED stays on
  for (int k = 0; k < RING_LEDS; k++) {
    int32_t d = head - k * 256;  // how far the head is past this ring position
    if (d < -ring / 2) d += ring;  // wrap to (-ring/2, ring/2]
    if (d > ring / 2) d -= ring;
    uint8_t level = SPIN_BASE;
    if (d >= 0 && d < SPIN_TAIL) {
      level = 255 - ((255 - SPIN_BASE) * d) / SPIN_TAIL;  // tail behind the head
    } else if (d < 0 && d > -SPIN_LEAD) {
      level = 255 - ((255 - SPIN_BASE) * -d) / SPIN_LEAD;  // ramp in ahead of it
    }
    int i = k < CENTER_LED ? k : k + 1;  // ring position -> data index, skipping the middle
    leds[i] = colour;
    leds[i].nscale8(level);
  }
  FastLED.setBrightness(brightness);
  FastLED.show();
}

// Block for at least ms while spinning the ring in colour. Replaces delay() during the
// boot network stages, which run before the UDP task exists so no lock is needed.
void spinDelay(CRGB colour, unsigned long ms) {
  unsigned long start = millis();
  do {
    renderSpinFrame(colour, maxBrightness);
    delay(20);
  } while (millis() - start < ms);
}

// ---- BOOT button ----
// Polled from loop(); GPIO 0 is readable once the firmware is running. Hold 3 s: the ring
// blinks red, release to unlock the settings for UNLOCK_WINDOW_MS without the PIN. Keep
// holding: the blink speeds up at 7 s and the settings are erased at 10 s (blue), then
// the unit reboots. Release before 10 s and nothing is erased. Do not hold BOOT while
// powering on or pressing RESET: GPIO 0 low at reset enters the USB bootloader instead.
static uint32_t btnDownMs = 0;
static bool btnArmed = false;
volatile bool ledOverride = false;  // countdown / flash owns the ring; setTallyState() and the spin wait

void buttonTick() {
  uint32_t now = millis();
  if (digitalRead(RESET_BUTTON_PIN) == LOW) {
    if (!btnDownMs) { btnDownMs = now; btnArmed = false; }
    uint32_t held = now - btnDownMs;
    if (held < BTN_UNLOCK_MS) return;
    if (!btnArmed) {
      btnArmed = true;
      ledOverride = true;
      Serial.println("[Button] Held 3 s: release to unlock settings, keep holding for factory reset");
    }
    if (held >= BTN_RESET_MS) {
      Serial.println("[Button] Held 10 s: factory reset");
      ledLock();
      FastLED.setBrightness(maxBrightness);
      fill_solid(leds, NUM_LEDS, CRGB::Blue);
      FastLED.show();
      ledUnlock();
      resetSettings();
      delay(1000);
      ESP.restart();
    }
    uint32_t period = held < BTN_FAST_FROM_MS ? 400 : 120;  // red countdown, faster near the end
    ledLock();
    FastLED.setBrightness(maxBrightness);
    fill_solid(leds, NUM_LEDS, ((now / period) % 2) ? CRGB::Red : CRGB::Black);
    FastLED.show();
    ledUnlock();
  } else if (btnDownMs) {
    btnDownMs = 0;
    if (btnArmed) {
      btnArmed = false;
      ledOverride = false;
      lockPhysicalUnlock(UNLOCK_WINDOW_MS);
      Serial.printf("[Button] Settings unlocked for %lu minutes\n", UNLOCK_WINDOW_MS / 60000UL);
      setTallyState(tslState, tslBrightness);  // back to the tally
    }
  }
}

// WARNING: onEvent is called from a separate FreeRTOS task (thread)!
void onEvent(arduino_event_id_t event) {
  switch (event) {
    case ARDUINO_EVENT_ETH_START:
      Serial.println("ETH Started");
      // The hostname must be set after the interface is started, but needs
      // to be set before DHCP, so set it from the event handler thread.
      ETH.setHostname(deviceHostname.c_str());
      break;
    case ARDUINO_EVENT_ETH_CONNECTED: Serial.println("ETH Connected"); break;
    case ARDUINO_EVENT_ETH_GOT_IP:
      Serial.println("ETH Got IP");
      Serial.println(ETH);
      eth_connected = true;
      break;
    case ARDUINO_EVENT_ETH_LOST_IP:
      Serial.println("ETH Lost IP");
      eth_connected = false;
      break;
    case ARDUINO_EVENT_ETH_DISCONNECTED:
      Serial.println("ETH Disconnected");
      eth_connected = false;
      break;
    case ARDUINO_EVENT_ETH_STOP:
      Serial.println("ETH Stopped");
      eth_connected = false;
      break;
    case ARDUINO_EVENT_WIFI_STA_GOT_IP:
      Serial.println("WiFi Got IP");
      Serial.println(WiFi.localIP());
      wifi_connected = true;
      break;
    case ARDUINO_EVENT_WIFI_STA_DISCONNECTED:
      Serial.println("WiFi Disconnected");
      wifi_connected = false;
      break;
    case ARDUINO_EVENT_WIFI_AP_START:
      Serial.println("AP Started");
      ap_mode = true;
      break;
    case ARDUINO_EVENT_WIFI_AP_STOP:
      Serial.println("AP Stopped");
      ap_mode = false;
      break;
    default: break;
  }
}

// Get the active IP address (Ethernet preferred, then WiFi, then AP)
String getActiveIP() {
  if (eth_connected) {
    return ETH.localIP().toString();
  } else if (wifi_connected) {
    return WiFi.localIP().toString();
  } else if (ap_mode) {
    return WiFi.softAPIP().toString();
  }
  return "0.0.0.0";
}

// Get connection status string
String getConnectionStatus() {
  String status = "";
  if (eth_connected) status += "Ethernet";
  if (wifi_connected) {
    if (status.length() > 0) status += " + ";
    status += "WiFi";
  }
  if (ap_mode) {
    if (status.length() > 0) status += " + ";
    status += "AP";
  }
  if (status.length() == 0) status = "Disconnected";
  return status;
}

// Try to connect to WiFi
bool setupWiFi() {
  if (!wifiEnabled || wifiSSID.length() == 0) {
    Serial.println("WiFi not configured or disabled");
    return false;
  }

  Serial.printf("Connecting to WiFi: %s\n", wifiSSID.c_str());

  // Make sure WiFi is in a clean state
  WiFi.disconnect(true);
  delay(100);
  yield();

  WiFi.setHostname(deviceHostname.c_str());
  WiFi.mode(WIFI_STA);
  WiFi.setSleep(false);  // modem sleep adds tens of ms to every received packet
  delay(100);
  yield();

  WiFi.begin(wifiSSID.c_str(), wifiPassword.c_str());

  unsigned long startTime = millis();
  unsigned long lastDot = 0;
  while (WiFi.status() != WL_CONNECTED && millis() - startTime < WIFI_CONNECT_TIMEOUT) {
    yield();  // Feed the watchdog
    // Spin purple while connecting
    renderSpinFrame(CRGB::Purple, maxBrightness);
    delay(20);
    if (millis() - lastDot >= 500) {
      lastDot = millis();
      Serial.print(".");
    }
  }
  Serial.println();

  fill_solid(leds, NUM_LEDS, CRGB::Black);
  FastLED.show();

  if (WiFi.status() == WL_CONNECTED) {
    Serial.printf("WiFi connected! IP: %s\n", WiFi.localIP().toString().c_str());
    wifi_connected = true;
    return true;
  } else {
    Serial.println("WiFi connection failed");
    WiFi.disconnect(true);
    return false;
  }
}
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
void loop() {
  buttonTick();

  // Handle DNS requests for captive portal (AP mode only)
  if (ap_mode) {
    dnsServer.processNextRequest();
  }

  // Handle disco mode animation
  if (discoMode) {
    if (millis() < discoEndTime) {
      // Random rainbow color changes - all LEDs same color, distinct hues
      static unsigned long lastColorChange = 0;
      if (millis() - lastColorChange > 250) {  // Change every 250ms
        lastColorChange = millis();
        // Pick a random hue from 6 distinct rainbow colors (avoid in-between muddy colors)
        uint8_t hueOptions[] = {0, 32, 64, 96, 160, 192};  // Red, Orange, Yellow, Green, Blue, Purple
        uint8_t randomHue = hueOptions[random(6)];
        ledLock();
        FastLED.setBrightness(255);  // Full brightness for disco
        fill_solid(leds, NUM_LEDS, CHSV(randomHue, 255, 255));
        FastLED.show();
        ledUnlock();
      }
    } else {
      // Disco time is over
      discoMode = false;
      Serial.println("[DISCO] Party's over!");
      setTallyState(tslState, tslBrightness);  // back to what the switcher last sent
    }
  }

  // Keep the spin animation turning while a tally is active. Disco owns the LEDs
  // while it runs; setTallyState() restarts the spin when it ends.
  static unsigned long lastSpinFrame = 0;
  if (spinActive && !discoMode && !ledOverride && millis() - lastSpinFrame >= 25) {
    lastSpinFrame = millis();
    ledLock();
    if (spinActive) renderSpinFrame(tallyColour, tallyLevel);
    ledUnlock();
  }

  // Handle web server requests
  server.handleClient();

  // Handle OTA updates
  ArduinoOTA.handle();

  // Periodic background device discovery (every 60 seconds)
  static unsigned long lastAutoDiscovery = 0;
  if ((eth_connected || wifi_connected) && !ap_mode) {
    if (millis() - lastAutoDiscovery > 60000) {
      lastAutoDiscovery = millis();
      discoverTallyDevices();
    }
  }

  delay(10);
}

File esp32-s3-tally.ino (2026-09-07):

/*
    ESP32-S3 TSL Tally Light with Web Configuration
    Video Walrus 2025
*/

#include <FastLED.h>
#include <Preferences.h>
#include <ESPAsyncWebServer.h>

#define BUFFER_LENGTH 256
#define NUM_LEDS 7
#define DATA_PIN 16
#define RESET_BUTTON_PIN 0  // GPIO 0 (BOOT button) for factory reset

// Important to be defined BEFORE including ETH.h for ETH.begin() to work.
#define ETH_PHY_ADDR 1
#define ETH_PHY_POWER   5
#define ETH_PHY_MDC   23
#define ETH_PHY_MDIO  18
#define ETH_CLK_MODE ETH_CLOCK_GPIO0_OUT
#define ETH_PHY_TYPE ETH_PHY_W5500

#include <ETH.h>
#include <NetworkUdp.h>
#include <AsyncUDP.h>
#include <ArduinoOTA.h>

// Forward declarations
void loadSettings();
void saveSettings();
void resetSettings();
void checkResetButton();
void onEvent(arduino_event_id_t event);
void setupWebServer();
String getConfigPage();
void udpTSL(char *data);

// Web server
AsyncWebServer server(80);
Preferences preferences;

int MAXbright = 50;

// Configurable settings (loaded from NVS)
int tslAddress = 0;
bool useDHCP = true;
String staticIP = "192.168.1.100";
String gateway = "192.168.1.1";
String subnet = "255.255.255.0";
String dns = "8.8.8.8";
String deviceHostname = "ESP-TSL-Tally";

bool redTally = false;
int redLED = false;
bool greenTally = false;
int greenLED = false;

IPAddress multicastAddress(239, 1, 2, 3);
unsigned int multicastPort = 8901;

AsyncUDP udp;

CRGB leds[NUM_LEDS];

static bool eth_connected = false;
String currentTallyState = "Off";

// Load settings from NVS
void loadSettings() {
  preferences.begin("tally", true);  // read-only
  tslAddress = preferences.getInt("tslAddress", 0);
  useDHCP = preferences.getBool("useDHCP", true);
  staticIP = preferences.getString("staticIP", "192.168.1.100");
  gateway = preferences.getString("gateway", "192.168.1.1");
  subnet = preferences.getString("subnet", "255.255.255.0");
  dns = preferences.getString("dns", "8.8.8.8");
  deviceHostname = preferences.getString("hostname", "ESP-TSL-Tally");
  preferences.end();

  Serial.println("Settings loaded:");
  Serial.printf("  TSL Address: %d\n", tslAddress);
  Serial.printf("  DHCP: %s\n", useDHCP ? "Yes" : "No");
  if (!useDHCP) {
    Serial.printf("  Static IP: %s\n", staticIP.c_str());
    Serial.printf("  Gateway: %s\n", gateway.c_str());
    Serial.printf("  Subnet: %s\n", subnet.c_str());
    Serial.printf("  DNS: %s\n", dns.c_str());
  }
  Serial.printf("  Hostname: %s\n", deviceHostname.c_str());
}

// Save settings to NVS
void saveSettings() {
  preferences.begin("tally", false);  // read-write
  preferences.putInt("tslAddress", tslAddress);
  preferences.putBool("useDHCP", useDHCP);
  preferences.putString("staticIP", staticIP);
  preferences.putString("gateway", gateway);
  preferences.putString("subnet", subnet);
  preferences.putString("dns", dns);
  preferences.putString("hostname", deviceHostname);
  preferences.end();
  Serial.println("Settings saved to NVS");
}

// Reset settings to factory defaults
void resetSettings() {
  preferences.begin("tally", false);
  preferences.clear();
  preferences.end();
  Serial.println("Settings reset to factory defaults");

  // Reset to defaults in memory
  tslAddress = 0;
  useDHCP = true;
  staticIP = "192.168.1.100";
  gateway = "192.168.1.1";
  subnet = "255.255.255.0";
  dns = "8.8.8.8";
  deviceHostname = "ESP-TSL-Tally";
}

// Check if reset button is held during boot
void checkResetButton() {
  pinMode(RESET_BUTTON_PIN, INPUT_PULLUP);

  if (digitalRead(RESET_BUTTON_PIN) == LOW) {
    Serial.println("Reset button pressed, hold for 3 seconds to reset...");
    unsigned long startTime = millis();

    // Flash LEDs to indicate reset mode
    while (digitalRead(RESET_BUTTON_PIN) == LOW) {
      if (millis() - startTime > 3000) {
        Serial.println("Resetting to factory defaults!");
        fill_solid(leds, NUM_LEDS, CRGB::Blue);
        FastLED.show();
        resetSettings();
        delay(1000);
        fill_solid(leds, NUM_LEDS, CRGB::Black);
        FastLED.show();
        break;
      }
      // Blink red while waiting
      fill_solid(leds, NUM_LEDS, ((millis() / 200) % 2) ? CRGB::Red : CRGB::Black);
      FastLED.show();
      delay(50);
    }
    fill_solid(leds, NUM_LEDS, CRGB::Black);
    FastLED.show();
  }
}

// WARNING: onEvent is called from a separate FreeRTOS task (thread)!
void onEvent(arduino_event_id_t event) {
  switch (event) {
    case ARDUINO_EVENT_ETH_START:
      Serial.println("ETH Started");
      // The hostname must be set after the interface is started, but needs
      // to be set before DHCP, so set it from the event handler thread.
      ETH.setHostname(deviceHostname.c_str());
      break;
    case ARDUINO_EVENT_ETH_CONNECTED: Serial.println("ETH Connected"); break;
    case ARDUINO_EVENT_ETH_GOT_IP:
      Serial.println("ETH Got IP");
      Serial.println(ETH);
      eth_connected = true;
      break;
    case ARDUINO_EVENT_ETH_LOST_IP:
      Serial.println("ETH Lost IP");
      eth_connected = false;
      break;
    case ARDUINO_EVENT_ETH_DISCONNECTED:
      Serial.println("ETH Disconnected");
      eth_connected = false;
      break;
    case ARDUINO_EVENT_ETH_STOP:
      Serial.println("ETH Stopped");
      eth_connected = false;
      break;
    default: break;
  }
}

void udpTSL(char *data) {
  char* message;
  int T;
  int Bright;
  int addr;
  String text;
  message = data;

  addr = message[0] - 128;

  if (tslAddress == addr) {
    T = message[1] & 0b00001111;

    for (int j = 2; j < 17; j++) {
      text += message[j];
    }
    Serial.println(text);

    Bright = message[1] & 0b00110000;
    Bright = Bright >> 4;
    Bright = map(Bright, 0, 3, 0, MAXbright);
    Serial.println(Bright);
    FastLED.setBrightness(Bright);

    switch (T) {
      case 0:
        fill_solid(leds, NUM_LEDS, CRGB::Black);
        currentTallyState = "Off";
        Serial.println("Off");
        break;
      case 1:
        fill_solid(leds, NUM_LEDS, CRGB::Green);
        currentTallyState = "Green";
        Serial.println("Green");
        break;
      case 2:
        fill_solid(leds, NUM_LEDS, CRGB::Red);
        currentTallyState = "Red";
        Serial.println("Red");
        break;
      case 3:
        fill_solid(leds, NUM_LEDS, CRGB::Yellow);
        currentTallyState = "Yellow";
        Serial.println("Yellow");
        break;
      default:
        fill_solid(leds, NUM_LEDS, CRGB::Black);
        currentTallyState = "Off";
        Serial.println("Off*");
    }
    FastLED.show();
  }
}
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

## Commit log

2025-12-29 first v
    [housing.3mf]
2025-12-29 Add multi-device discovery, captive portal, and unique device IDs
    - Multi-device discovery via mDNS with Network Devices section in web UI
    - Bulk control buttons to test all devices simultaneously
    - Captive portal for automatic config page popup in AP mode
    - Unique hostnames and AP SSIDs based on ESP32 chip ID
    - Web interface factory reset button with confirmation
    - New API endpoints: /info, /discover, /reset
    [main.cpp]
2025-12-29 Fix W5500 Ethernet initialization and simplify network mode
    - Fix ETH.begin() with correct ETH_PHY_* defines before ETH.h include
    - Add yield() calls to prevent watchdog timeout during network setup
    - Simplify to single-interface mode: Ethernet OR WiFi (not both)
    - Ethernet takes priority when connected, WiFi/AP as fallback
    - Extend Ethernet connection timeout to 10 seconds
    - Update README with correct SPI pin documentation
    [main.cpp]
2025-12-31 Add GitHub OTA updates, auto-discovery, and release tooling
    - GitHub release checking with one-click firmware update from web UI
    - Auto-discovery of tally devices on page load and every 60 seconds
    - ArduinoOTA.handle() fix for local network OTA support
    - OTA environment in platformio.ini for single device updates
    - Bulk OTA update script (ota-update-all.sh)
    - Release script for creating GitHub releases (release.sh)
    - Quick start guide for new users (QUICKSTART.md)
    - Updated README with OTA and GitHub update documentation
    [main.cpp]
2025-12-31 Fix HTTPS for GitHub OTA updates
    - Add WiFiClientSecure for HTTPS connections
    - Use setInsecure() to skip certificate verification
    - Fix checkForUpdates() and performOTAUpdate() to work with GitHub API
    [main.cpp]
2025-12-31 Fix Check button styling and update flow
    - Make Check button inline with firmware version (width:auto)
    - Remove blocking alert() dialog before update fetch
    - Show "Updating..." status inline instead of alert
    [main.cpp]
2026-01-01 Add CORS headers, fix discovery duplicates, extend disco mode
    - Add Access-Control-Allow-Origin headers to /status, /test, /info, /disco, /disco-stop
    - Fix duplicate device detection in mDNS discovery
    - Extend disco mode duration to 30 seconds (max 120)
    - Simplify ota-update-all.sh to require device IP argument
    - Suppress verbose PlatformIO output in bulk update script
    [housing.3mf]
2026-01-05 Fix TSL text parsing and add auto-refresh status polling
    - Strip null bytes and non-printable chars from TSL text field
    - Fix JSON parse error in browser caused by null bytes
    - Add 2-second auto-refresh for tally state in web UI
    - Separate status and device polling intervals
    [main.cpp]
2026-01-11 Change Ethernet wait LED to pulsing orange, update copyright to 2026
    - Ethernet connection wait now shows pulsing orange instead of blinking green
    - Updated web page copyright year to 2026
2026-02-05 Fix static IP configuration for Ethernet
    Move ETH.config() call to immediately after ETH.begin() returns.
    This prevents the DHCP client from starting while ensuring the
    network interface is initialized before applying static IP settings.
    Previously ETH.config() was called before ETH.begin() which was
    completely ignored by the ESP32 network stack.
    [main.cpp]
2026-09-02 Fix iOS captive-portal auto-focus, TSL tally masking, and HTML/JSON escaping
    Web UI (iOS Captive Network Assistant):
    - In AP mode all inputs start readonly and the WiFi password is a CSS-masked
    text input, so the CNA finds no login form to auto-focus
    - Focus guard rejects programmatic focus unless it follows a tap on that field
    or its label, a keypress, or a move from another control; readonly returns
    whenever a field loses focus
    - Test buttons call preventDefault() on touch events, removing the synthetic
    mouse events that double-fired /test and re-opened the focus window
    - Tally/status DOM writes only happen when a value changed
    - Inputs get font-size 16px (no iOS zoom on focus); la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
    [main.cpp]
2026-09-02 Apply TSL brightness to LEDs and restore TSL state after test buttons
    - setTallyState() takes an optional brightness; udpTSL() passes the mapped
    TSL level instead of having it overwritten by maxBrightness before show()
    - Remember the last TSL state/brightness; /test?restore=1 returns to it and
    the web UI test buttons call it on release instead of forcing Off
    Claude-Session: https://claude.ai/code/session_01PfENH3MM4qFLYrjjgyfkqt
2026-09-02 Bring README and QUICKSTART in line with the firmware; drop unused async libs
    - Remove TSL 5.0, extended tally states 4-6 and the extra test buttons the
    firmware never had; document the three test buttons, restore-on-release,
    the TSL brightness mapping, control-byte bit usage and the AP-mode limits
    - Add the missing endpoints (/test?restore, /disco, /disco-stop, captive
    probes), the build stamp in /info, disco mode, and the real factory-reset
    timing window
    - Fix pin table (no ETH power pin), LED patterns, heading levels, copyright
    - platformio.ini: remove ESPAsyncWebServer/AsyncTCP, which nothing includes;
    README listing now mirrors the file including [platformio] and [env:ota]
    Co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
2026-09-03 Add WiFi network scan to the config page
    New /api/wifi-scan endpoint runs an async scan (?start=1 to begin, poll
    until scanning is false) and returns SSID, RSSI, channel and encryption.
    The WiFi Settings card gets a "Scan for Networks" button that lists
    nearby networks strongest first, one row per SSID, and fills in the
    SSID on tap. Works over Ethernet, WiFi and in AP mode.
    Also add a utf-8 charset meta so non-ASCII SSIDs round-trip, and give
    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
2026-09-06 Add LED Animation setting with a ring spin for tally and boot stages
    The seven LEDs are one in the middle and six in a ring. Spin keeps the
    middle LED on, holds the ring at a dim base level and sweeps a bright
    head with a fading tail round the six. A new LED Animation setting
    (Solid/Spin, stored in NVS) applies it to an active tally; the
    Ethernet, WiFi and AP boot stages always use it in their stage colour,
    replacing the old pulse and blink patterns.
    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
2026-09-07 Rework the web page and move OTA updates to the S3 release manifest
    Web page is now static HTML in PROGMEM (src/webpage.h) that fills itself
    from /api/config and /status, instead of a String built per request.
    Operation / Configuration / System tabs, Auto/Light/Dark theme, and a
    header with hostname, IP and connection. Save applies TSL address,
    brightness and animation live with a toast; only hostname, network,
    WiFi, multicast and port changes reboot. Hostname is sanitised and IP
    fields validated. Update check opens a modal with release notes and
    Install/Later, the install poll aborts on a dead connection and offers
    Reload after two minutes, and a What's New popup shows once per browser
    afte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
    [main.cpp]
2026-09-07 Track PRD and progress notes; tidy workspace files
    Add PRD.md and progress.txt (updated for the v1.1.0 web page and S3
    manifest OTA), mark the pioarduino extension unwanted in VS Code, mirror
    the label/font-size CSS tweak into the legacy .ino, and drop the
    superseded housing.3mf.
    [housing.3mf]
2026-09-07 Signed firmware over pinned TLS, settings PIN, runtime BOOT button
    OTA: manifest and binary are fetched over TLS validated against Amazon's
    root CAs compiled into the firmware (src/certs.h); SNTP is started once
    online and the update check waits for a valid clock. Every release is
    signed with ECDSA P-256 (private key in the macOS Keychain or
    ~/.config/videowalrus, public key in src/signing_key.h). The device
    hashes the download as it streams into the passive partition and
    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
2026-09-07 Add Tally Arbiter listener mode as an alternative tally source
    New Tally Source setting: TSL 3.1 multicast (default, unchanged) or
    Tally Arbiter. In Arbiter mode a socket.io client (src/arbiter.cpp,
    Links2004 WebSockets + ArduinoJson) runs on core 0 in place of the UDP
    task, registers with the server as a listener client and follows one
    device: program lights red, preview green, both yellow, other buses
    ignored. device_states updates feed the same state variables as TSL so
    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
2026-09-08 Drain the TSL socket each pass, stop per-packet logging, redraw on change
    The UDP task handled one packet per 5 ms pass and printed a line for
    every frame of every address, capping intake near 200 packets/s; a
    switcher repeating all addresses several times a second overran it and
    the backlog showed as a lagging light. It now drains up to 64 queued
    packets per pass, sleeps 1 ms, parses without String, only looks at the
    address byte of frames for other addresses, trims the label's padding,
    and calls setTallyState() only when state, brightness or text changed.
    A summary line every 10 s replaces the per-packet log. WiFi modem sleep
    is disabled: it adds latency and drops multicast.
    Bench (WiFi,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
    [main.cpp]
